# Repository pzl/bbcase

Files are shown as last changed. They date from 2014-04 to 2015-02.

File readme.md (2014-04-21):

bbcase
------

I wanted a 3D-printed case for my busblaster, and this is the result. I modeled the actual bus blaster (v4.1a) first (see: busblaster.scad) and created a case around that model.

The case bottom has grooves to fit the protruding pins. The case top has cutouts for the jumpers and main pin header. There is a little extra cutout in the header section, and angled edge to allow a viewing window to the silkscreened pin labels on the board itself. The top case has a hole to fit the USB port, and two viewing windows and reflectors for the power and act LEDs, to be viewed from the side.

I put an optional cutout above the FPGA to allow some heat to escape, that file is not included here, but is in the STL

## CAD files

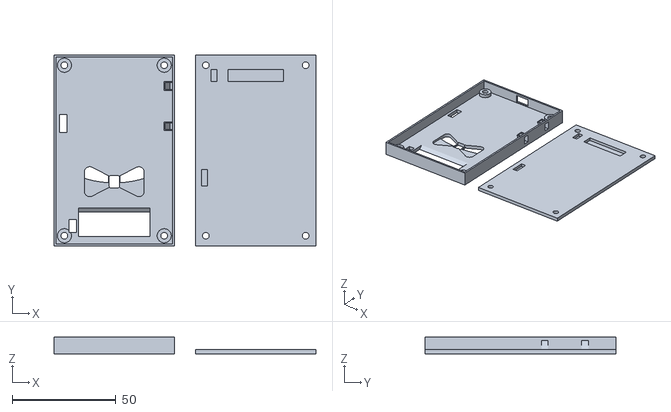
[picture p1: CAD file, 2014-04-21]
bbcase.stl
126.0 x 92.0 x 8.00

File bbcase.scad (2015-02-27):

use <busblaster.scad>;
use <bowtie.scad>;

$fn=100;

height=2;
bbwidth=56;
bblength=90;
bbheight=1.6;


screw_r=1.6;
screw_offset=2.4;

sidewall=1;


module bottom(){


	difference(){
		translate([(-bbwidth)/2-sidewall,(-bblength)/2-sidewall,0]){
			cube([bbwidth+sidewall*2,bblength+sidewall*2,height]);
		}

		//main pins cutout
		translate([-26.8/2,bblength/2-5.8+1-7,height-1.69]){
			cube([26.8,5.8,1.7]);
		}

		//power jumper cutout
		translate([-bbwidth/2+7.4-1,bblength/2-5.8+1-7,height-1.69]){
			cube([3,5.8,1.7]);
		}

		//mode jumper cutout
		translate([-bbwidth/2+2.9-1,-bblength/2+28.9-1,height-1.69]){
			cube([3,8,1.7]);
		}

		//screw holes
		translate([-bbwidth/2+screw_r+screw_offset,-bblength/2+screw_r+screw_offset,-1]){
			cylinder(h=height+2,r=screw_r);
		}
		translate([bbwidth/2-screw_r-screw_offset,-bblength/2+screw_r+screw_offset,-1]){
			cylinder(h=height+2,r=screw_r);
		}
		translate([-bbwidth/2+screw_r+screw_offset,bblength/2-screw_r-screw_offset,-1]){
			cylinder(h=height+2,r=screw_r);
		}
		translate([bbwidth/2-screw_r-screw_offset,bblength/2-screw_r-screw_offset,-1]){
			cylinder(h=height+2,r=screw_r);
		}


	}
}

module top(){
	upper=6;
	sz=height+.2;
	L=34.2;
	
	difference(){


		//top plate and screw reinforcements
		union(){
			translate([(-bbwidth)/2-sidewall,(-bblength)/2-sidewall,upper+height]){
				cube([bbwidth+sidewall*2,bblength+sidewall*2,height]);
			}

			//screw guides
			translate([-bbwidth/2+screw_r+screw_offset,-bblength/2+screw_r+screw_offset,height+upper-2]){
				cylinder(h=2,r=screw_r+1.8);
			}
			translate([bbwidth/2-screw_r-screw_offset,-bblength/2+screw_r+screw_offset,height+upper-2]){
				cylinder(h=2,r=screw_r+1.8);
			}
			translate([-bbwidth/2+screw_r+screw_offset,bblength/2-screw_r-screw_offset,height+upper-2]){
				cylinder(h=2,r=screw_r+1.8);
			}
			translate([bbwidth/2-screw_r-screw_offset,bblength/2-screw_r-screw_offset,height+upper-2]){
				cylinder(h=2,r=screw_r+1.8);
			}
		}


		translate([0,bblength/2-30,upper+height+bbheight-1.61])
		scale(.2)
		bowtie(6,15);


		//main header
		translate([-33/2-.6,bblength/2-8.6-4.3-.6-4,upper+height-1]){
			cube([34.2,9.8+4,height+2]);
		}
		//viewing triangle for main header lableing
		translate([-33/2-0.6,bblength/2-8.6-4.3-.6-4-height,upper+height-.1]){
			polyhedron(points=[
					[0,0,0],
					[0,sz,0],
					[0,sz,sz],
					[L,0,0],
					[L,sz,0],
					[L,sz,sz]
				],
				triangles=[
					[0,1,2],
					[3,5,4],
					[2,5,3],
					[0,2,3],
					[2,4,5],
					[2,1,4],
					[0,3,4],
					[0,4,1]
			]);
		}
		

		//power jumper
		translate([-33/2-2.35-2.3-.6,bblength/2-5-6.2-.6,upper+height-4]){
			cube([2.35+1.2,5+1.2,height+5]);
		}

		//mode jumper
		translate([-bbwidth/2+2.2-.6,-bblength/2+28.3-.6,upper+height-1]){
			cube([2.4+1.2,7.5+1.2,height+2]);
		}

		//screw holes
		translate([-bbwidth/2+screw_r+screw_offset,-bblength/2+screw_r+screw_offset,upper-.1]){
			cylinder(h=height+3,r=screw_r);
		}
		translate([bbwidth/2-screw_r-screw_offset,-bblength/2+screw_r+screw_offset,upper-.1]){
			cylinder(h=height+3,r=screw_r);
		}
		translate([-bbwidth/2+screw_r+screw_offset,bblength/2-screw_r-screw_offset,upper-.1]){
			cylinder(h=height+3,r=screw_r);
		}
		translate([bbwidth/2-screw_r-screw_offset,bblength/2-screw_r-screw_offset,upper-.1]){
			cylinder(h=height+3,r=screw_r);
		}
	}

	//back wall
	translate([-bbwidth/2-sidewall,bblength/2,height]){
		cube([bbwidth+sidewall*2,sidewall,upper]);
	}
	//blank side wall
	translate([-bbwidth/2-sidewall,-bblength/2-sidewall,height]){
		cube([sidewall,bblength+sidewall*2,upper]);
	}

	//USB wall
	difference(){
		translate([-bbwidth/2-sidewall,-bblength/2-sidewall,height]){
			cube([bbwidth+sidewall*2,sidewall,upper]);
		}
		translate([-8.5/2,-bblength/2-sidewall-1,height+bbheight-.5]){
			cube([8.5,sidewall+2,4.5]);
		}
	}


	//LED wall
	difference(){
		translate([bbwidth/2,-bblength/2-sidewall,height]){
			cube([sidewall,bblength+sidewall*2,upper]);
		}
		//power square cutout
		translate([bbwidth/2-1,-bblength/2+13-.6,+height+bbheight]){
			cube([sidewall+2,2.1+1.2,upper-bbheight+.1]);
		}


		//ACT square cutout
		translate([bbwidth/2-1,-bblength/2+32.3-.6,+height+bbheight]){
			cube([sidewall+2,2.1+1.2,upper-bbheight+.1]);
		}
	}
	//power LED reflector
	difference(){
		hull(){
			translate([bbwidth/2-1.25-1.8-.6-.5,-bblength/2+13-.6-0.5,height+bbheight]){
				cube([1.25+1.8+.6+.5,2.1+1.2+1,.1]);
			}
	
			translate([bbwidth/2-sidewall-.5,-bblength/2+13-.6-.5,upper+height]){
				cube([sidewall+.5,2.1+1.2+1,.1]);
			}
		}
		hull(){
			translate([bbwidth/2-1.25-1.8-.5,-bblength/2+13-.6,height+bbheight-.1]){
				cube([1.25+1.8+.6+.5,2.1+1.2,.4]);
			}
			translate([bbwidth/2-sidewall,-bblength/2+13-.6,upper+height+.1]){
				cube([sidewall,2.1+1.2,.1]);
			}
		}
	}


	//ACT LED reflector
	difference(){
		hull(){
			translate([bbwidth/2-1.25-1.8-.6-.5,-bblength/2+32.3-.6-0.5,height+bbheight]){
				cube([1.25+1.8+.6+.5,2.1+1.2+1,.1]);
			}
	
			translate([bbwidth/2-sidewall-.5,-bblength/2+32.3-.6-.5,upper+height]){
				cube([sidewall+.5,2.1+1.2+1,.1]);
			}
		}
		hull(){
			translate([bbwidth/2-1.25-1.8-.5,-bblength/2+32.3-.6,height+bbheight-.1]){
				cube([1.25+1.8+.6+.5,2.1+1.2,.4]);
			}
			translate([bbwidth/2-sidewall,-bblength/2+32.3-.6,upper+height+.1]){
				cube([sidewall,2.1+1.2,.1]);
			}
		}
	}	

	
}

//translate([0,0,height])
//bb();

bottom();

rotate(a=[180,0,0])
translate([-bbwidth-sidewall*2-10,0,-10])
top();

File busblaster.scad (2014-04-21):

$fn=100;

module bb(){
	width=56;
	length=90;
	height=1.6;

	edge_radius=3.7;
	screw_r=1.6;

	screw_offset=2.4;
	

	difference(){
		//main PCB rectangle
		color("red")
		hull(){
			translate([-width/2+edge_radius,-length/2+edge_radius,0]){
				cylinder(h=height,r=edge_radius);
			}
			translate([-width/2+edge_radius,length/2-edge_radius,0]){
				cylinder(h=height,r=edge_radius);
			}
			translate([width/2-edge_radius,-length/2+edge_radius,0]){
				cylinder(h=height,r=edge_radius);
			}
			translate([width/2-edge_radius,length/2-edge_radius,0]){
				cylinder(h=height,r=edge_radius);
			}
		}

		//screw holes
		translate([-width/2+screw_r+screw_offset,-length/2+screw_r+screw_offset,-0.5]){
			color("orange")
			cylinder(h=height+1,r=screw_r);
		}
		translate([-width/2+screw_r+screw_offset,length/2-screw_r-screw_offset,-0.5]){
			color("orange")
			cylinder(h=height+1,r=screw_r);
		}
		translate([width/2-screw_r-screw_offset,-length/2+screw_r+screw_offset,-0.5]){
			color("orange")
			cylinder(h=height+1,r=screw_r);
		}
		translate([width/2-screw_r-screw_offset,length/2-screw_r-screw_offset,-0.5]){
			color("orange")
			cylinder(h=height+1,r=screw_r);
		}

	}
	
	//USB
	translate([-7.6/2,-length/2-0.6,height]){
		color("silver")
		cube([7.6,9.1,3.7]);
	}

	//pin header
	difference(){
		translate([-33/2,length/2-8.6-4.3,height]){
			color("darkslategrey")
			cube([33,8.6,10.6-height]);
		}
		//hollow center
		translate([-31/2,length/2-6.6-5.3,height+2.4]){
			color("darkslategrey")
			cube([31,6.6,10-height]);
		}
		//polarity notch
		translate([-4.5/2,length/2-13.8,height+2.15]){
			color("darkslategrey")
			cube([4.5,2,12]);
		}

		//side holes
		translate([33/2-1.02,length/2-8.6-3.3/2,height-0.1]){
			color("darkslategrey")
			cube([1.03,3.3,6.46]);
		}
		translate([-33/2-.01,length/2-8.6-3.3/2,height-0.1]){
			color("darkslategrey")
			cube([1.03,3.3,6.46]);
		}
	}

	//power jumper
	translate([-33/2-2.35-2.3,length/2-5-6.2,height]){
		color("darkslategrey")
		cube([2.35,5,10.2-height]);
	}

	//mode jumper
	translate([-width/2+2.2,-length/2+28.3,height]){
		color("darkslategrey")
		cube([2.4,7.5,10.2-height]);
	}



	//power led
	translate([width/2-1.25-1.8,-length/2+13,height]){
		color("white")
		cube([1.25,2.1,2.5-height]);
	}
	//resistor
	translate([width/2-.81-2,-length/2+9.2,height]){
		color("darkslategrey")
		cube([.81,1.7,0.35]);
	}

	//act led
	translate([width/2-1.25-1.8,-length/2+32.3,height]){
		color("white")
		cube([1.25,2.1,2.5-height]);
	}
	//resistor
	translate([width/2-.81-2,-length/2+32.3+4,height]){
		color("darkslategrey")
		cube([.81,1.7,0.35]);
	}


	//button
	translate([width/2-5.3-1.8,-length/2+20.6,height]){
		color("silver")
		cube([5.3,5.3,3.2-height]);
	}

	//crystal
	translate([-width/2+3.5/2+14.9,-length/2+3.5/2+7,height+4-2.8]){
		color("silver")
		hull(){
			cylinder(r=3.5/2,h=2.8);
			translate([0,9.9-3.5,0]){
				cylinder(r=3.5/2,h=2.8);
			}
		}
	}
	translate([-width/2+4.44/2+14.2,-length/2+4.44/2+6.1,height+4-2.8]){
		color("silver")
		hull(){
			cylinder(r=4.44/2,h=0.2);
			translate([0,11.2-4.44,0]){
				cylinder(r=4.44/2,h=0.2);
			}
		}
	}
	translate([-width/2+14.2,-length/2+6.1,height]){
		color("darkslategrey")
		cube([4.44,11.2,4-2.8]);
	}
	

	//UNDERSIDE

	//power jumper
	translate([-width/2+0.6+7.4,length/2-0.6-7,-1.3]){
		color("silver")
		cylinder(h=1.3,r1=0.25,r2=0.6);
	}
	translate([-width/2+0.6+7.4,length/2-0.6-7-2.7,-1.3]){
		color("silver")
		cylinder(h=1.3,r1=0.25,r2=0.6);
	}
	


	//mode jumper
	translate([-width/2+0.6+2.9,-length/2+28.9+0.6,-1.3]){
		color("silver")
		cylinder(h=1.3,r1=0.25,r2=0.6);
	}
	translate([-width/2+0.6+2.9,-length/2+28.9+0.6+2.4,-1.3]){
		color("silver")
		cylinder(h=1.3,r1=0.25,r2=0.6);
	}
	translate([-width/2+0.6+2.9,-length/2+28.9+0.6+2.4+2.7,-1.3]){
		color("silver")
		cylinder(h=1.3,r1=0.25,r2=0.6);
	}
	

	//header pins
	for (i=[0:9]){
		translate([-width/2+0.6+7.4+8.4+2.7*i,length/2-0.6-7,-1.3]){
			color("silver")
			cylinder(h=1.3,r1=0.25,r2=0.6);
		}
		translate([-width/2+0.6+7.4+8.4+2.7*i,length/2-0.6-7-2.7,-1.3]){
			color("silver")
			cylinder(h=1.3,r1=0.25,r2=0.6);
		}
	}



}

bb();

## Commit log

2014-04-21 add SCAD files and case STL
    [bbcase.scad, bbcase.stl, busblaster.scad]
2015-02-27 increase viewing window for JTAG labels
    [bbcase.scad]
